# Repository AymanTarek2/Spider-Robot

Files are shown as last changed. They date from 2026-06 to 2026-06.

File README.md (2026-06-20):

# Spider Robot — FreeRTOS-Controlled Quadruped

A 4-legged (12-DOF) walking robot built around an ESP32, with the full mechanical structure designed from scratch in SolidWorks — not a pre-made GrabCAD model. Each leg runs as an independent FreeRTOS task, giving the robot concurrent, non-blocking control over all four legs from a single microcontroller.

Spider pic

https://github.com/user-attachments/assets/da0e5ce1-07fc-4307-80b6-2c7e29078677

## Mechanical Design

The chassis, leg links, and head were modelled entirely in SolidWorks as an original design — full part files, the top-level assembly, and 3D-printable STLs are included in `Spider Solidworks/`. Each leg has 3 degrees of freedom (hip, knee, ankle), for 12 servo-driven joints total.

## Embedded Architecture

The robot is built on an ESP32 (`esp32doit-devkit-v1`) using FreeRTOS as the real-time scheduler, with all 12 servos driven through a PCA9685 PWM driver over I2C.

**Per-leg concurrency.** Each leg is its own FreeRTOS task (`Leg_1`–`Leg_4`), created with `xTaskCreate` at equal priority and left running an infinite loop. There's no central gait-sequencer dictating timing to the legs — each task independently reads a shared `movement_states` struct (forward / backward / left / right) and drives its own 3-joint motion sequence. Walking gait emerges from staggering each task's startup delay (0 ms, 600 ms, 900 ms, 300 ms), which phase-offsets the legs relative to each other.

**Non-blocking timing.** Every wait in the motion code uses `vTaskDelay()` rather than a blocking `delay()`, so the scheduler can interleave all four leg tasks on the single core without one leg stalling the others.

**Low-level PWM driver.** The PCA9685 driver is written directly against the I2C register map (mode/prescale/PWM registers) rather than using an off-the-shelf servo library — `pca9685_set_pwm_freq`, `pca9685_set_pwm`, and `set_servo_angle` handle frequency configuration and per-channel pulse-width control for all 12 channels.

**Motion primitives.** `angle_motion()` steps three joint angles toward a target simultaneously, and `move_spider_leg()` chains three of these calls (lift, swing, plant) into one leg-stride cycle, parameterized by direction sign and step delay.

**App control (currently disabled).** The firmware includes Blynk/Wi-Fi integration (`BLYNK_WRITE` handlers mapped to the same four movement flags) for phone-app control, but this path is commented out in the current build — the robot currently runs from the `movement_states` flags directly rather than over Wi-Fi.

## Tech Stack

- **MCU:** ESP32 (Arduino framework via PlatformIO)
- **RTOS:** FreeRTOS (per-leg tasks, `vTaskDelay`-based scheduling)
- **Actuation:** 12x servo motors via PCA9685 PWM driver (I2C, custom register-level driver)
- **Connectivity:** Blynk/Wi-Fi (implemented, currently disabled in firmware)
- **Mechanical design:** SolidWorks (original design), 3D-printed structure

## Repository Structure

```
Spider Code/        PlatformIO project - ESP32 firmware
  src/main.cpp       Entry point, Blynk handlers, movement_states
  src/main.c          Servo driver, gait logic, FreeRTOS leg tasks
  src/movement_states.h

Spider Solidworks/  Original CAD - parts, assembly, and STLs for 3D printing
```

## Status

This was a personal hardware project - full design-to-deployment cycle from CAD through 3D printing to embedded firmware on real hardware.

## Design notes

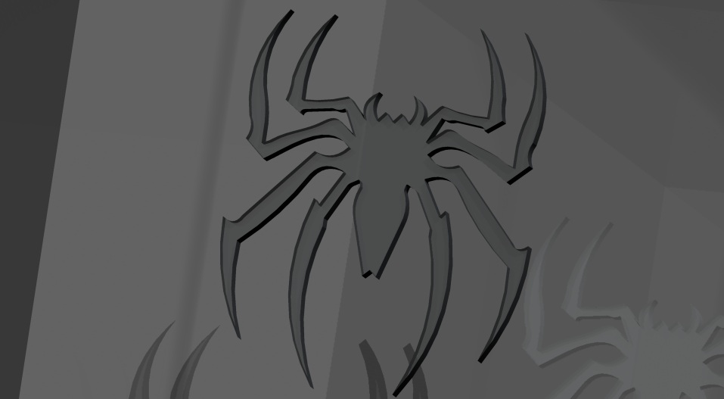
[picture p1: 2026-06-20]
Spider Solidworks/Renderings/sp1.jpg

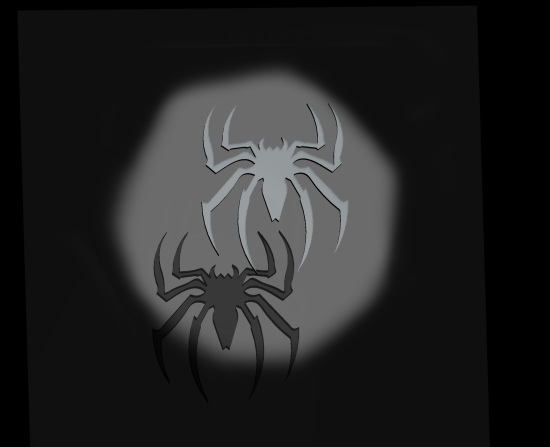
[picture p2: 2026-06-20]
Spider Solidworks/Renderings/ss2.jpg

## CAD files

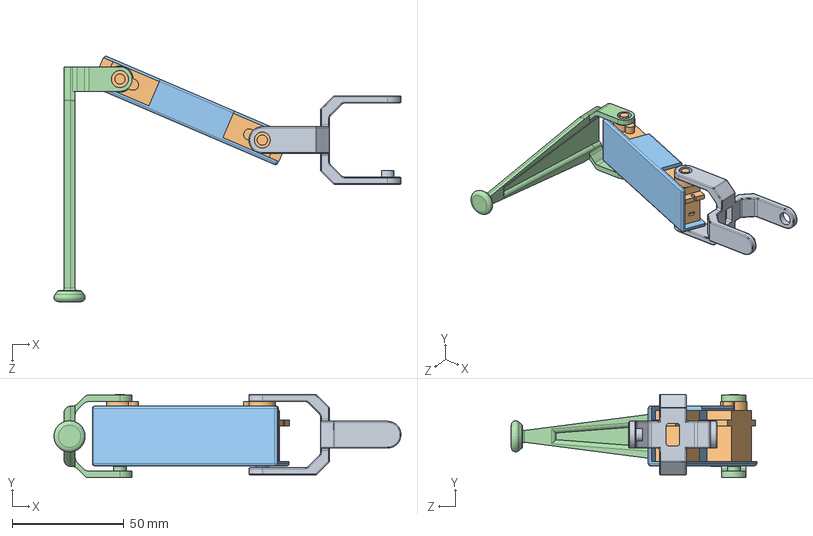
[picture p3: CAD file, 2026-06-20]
Spider Solidworks/Spider Arm.SLDASM
155.0 x 37.3 x 109.7 mm
Link1
User Library-Servo9G x 2
Link2
link3

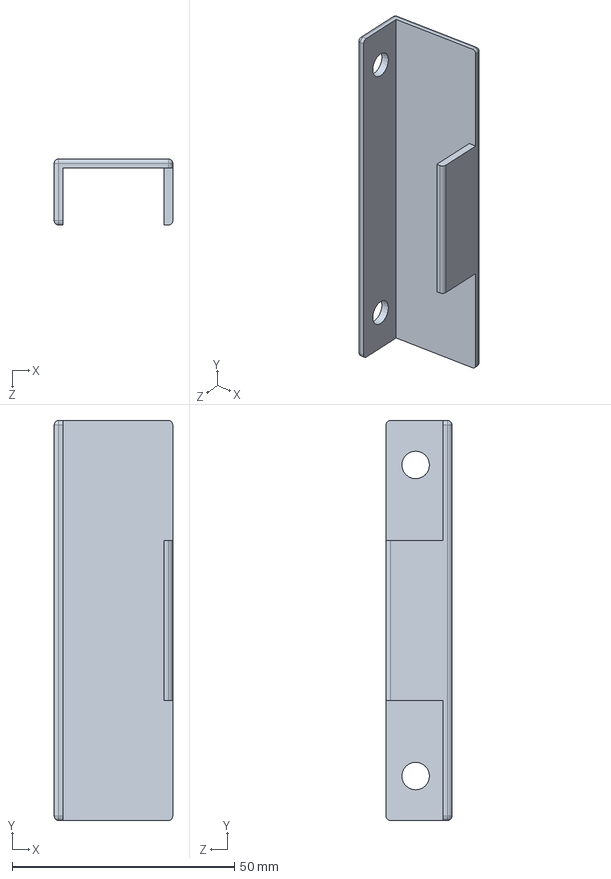
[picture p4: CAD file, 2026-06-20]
Spider Solidworks/Link2.SLDPRT
26.7 x 90.0 x 14.9 mm

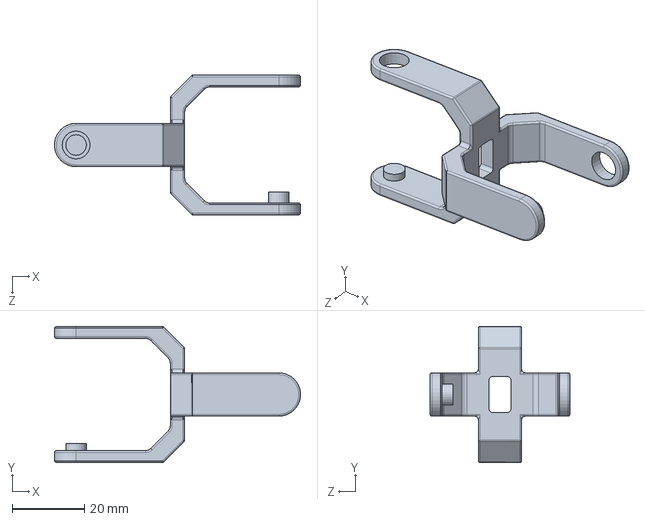
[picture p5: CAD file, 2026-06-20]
Spider Solidworks/Spider Robot stl 2/Link1.SLDPRT
67.9 x 37.6 x 38.6 mm

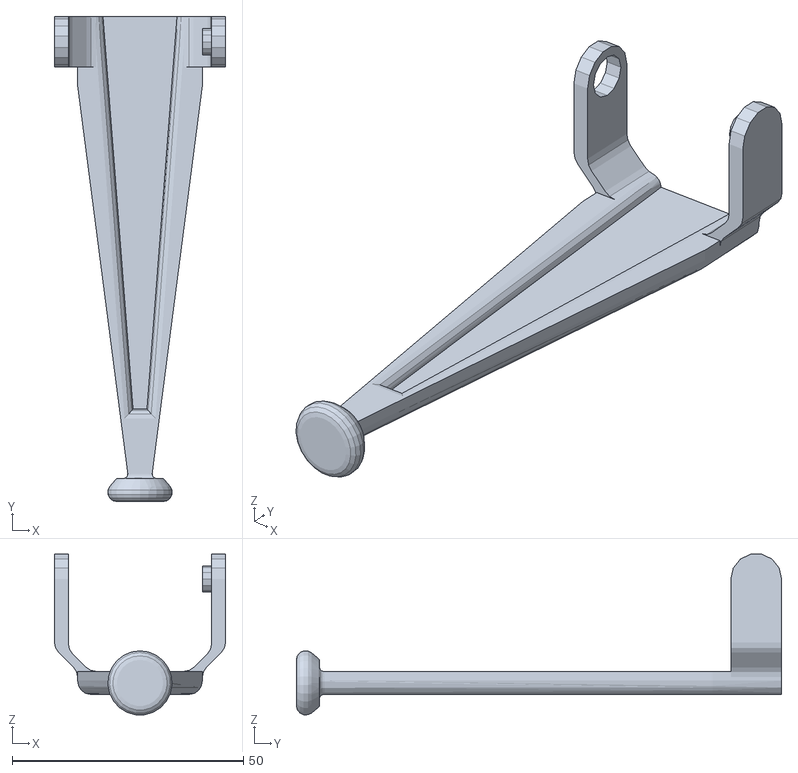
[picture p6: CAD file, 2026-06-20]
Spider Solidworks/Spider Robot stl 2/spider 3d print #4/link3 x4 .STL
37.0 x 105.0 x 34.8

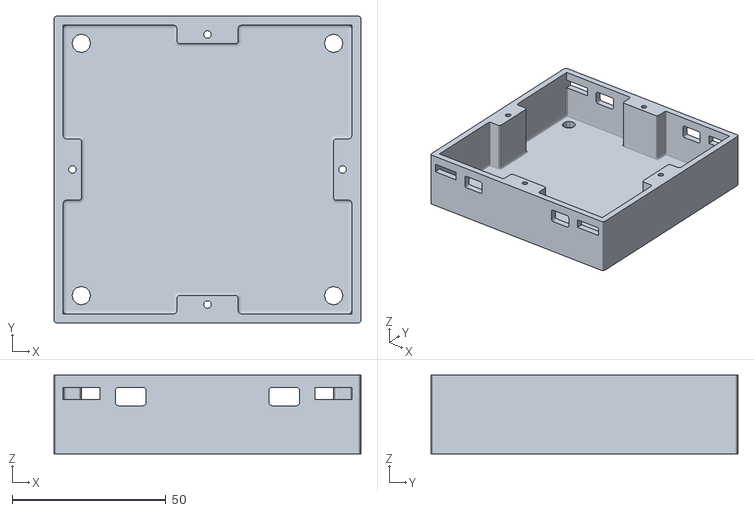
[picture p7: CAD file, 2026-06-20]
Spider Solidworks/Spider Robot stl/Body.STL
100.0 x 100.0 x 25.7

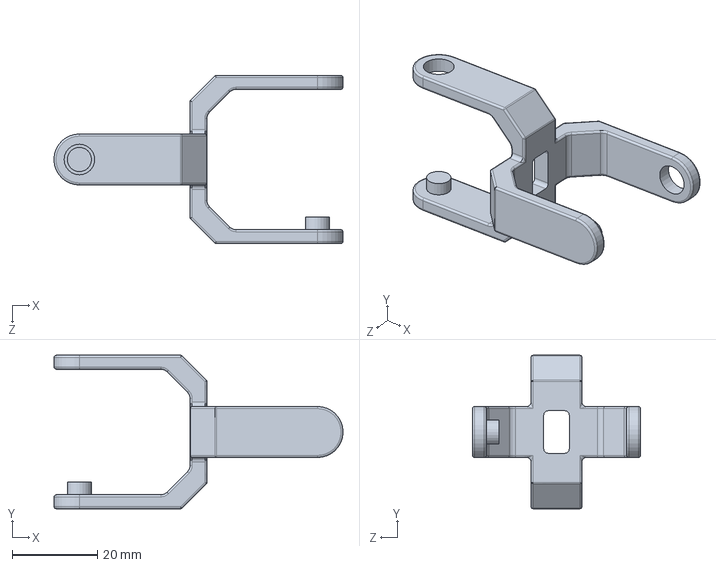
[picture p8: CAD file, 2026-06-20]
Spider Solidworks/Link1.SLDPRT
67.9 x 36.1 x 39.6 mm

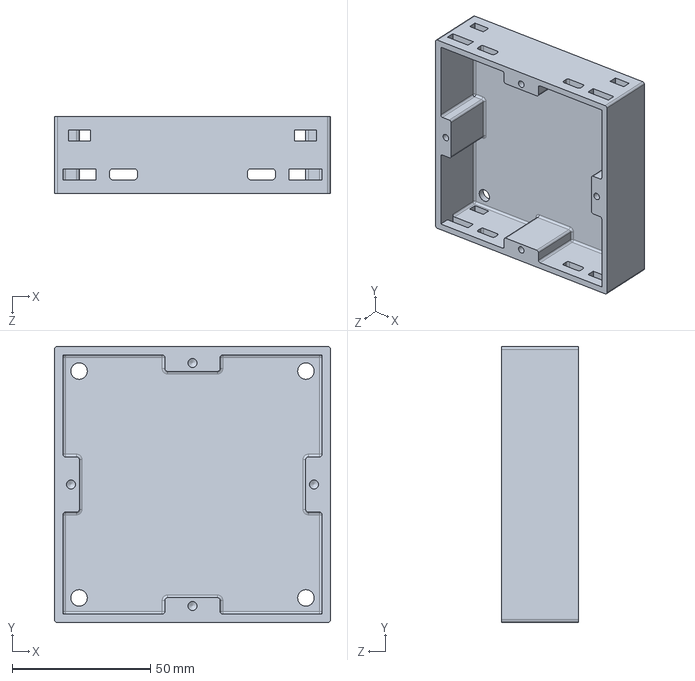
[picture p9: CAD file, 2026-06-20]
Spider Solidworks/Spider Robot stl 2/Body.SLDPRT
100.0 x 100.0 x 28.0 mm

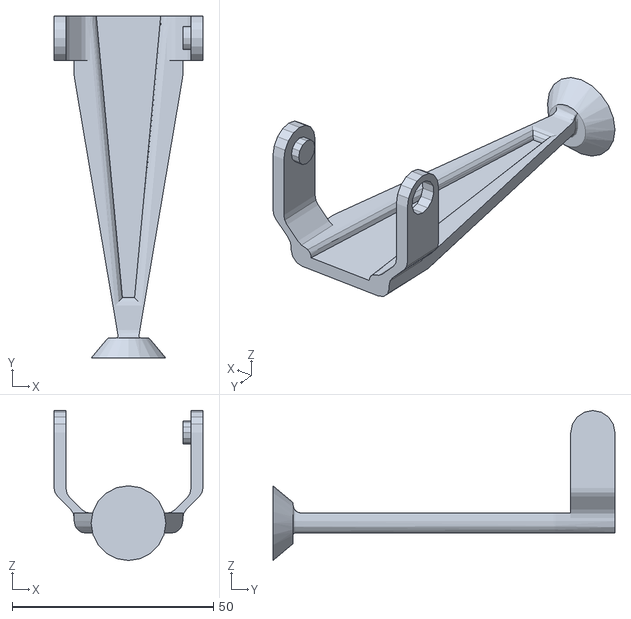
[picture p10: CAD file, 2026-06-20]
Spider Solidworks/Spider Robot stl 2/spider 3d print #3/link3.STL
37.0 x 85.0 x 37.3

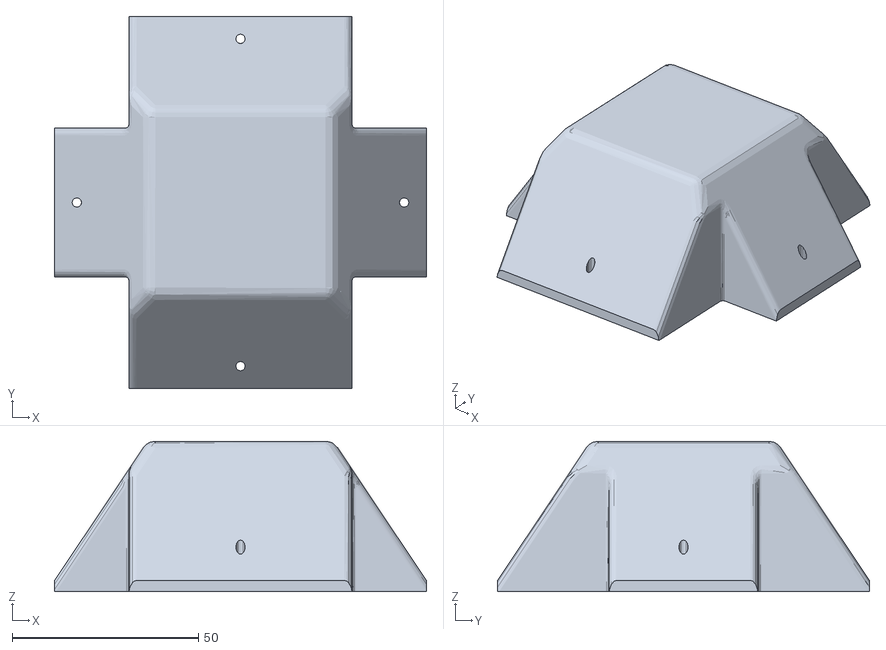
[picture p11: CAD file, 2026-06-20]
Spider Solidworks/Spider Robot stl/Upper Body.STL
100.0 x 100.0 x 40.4

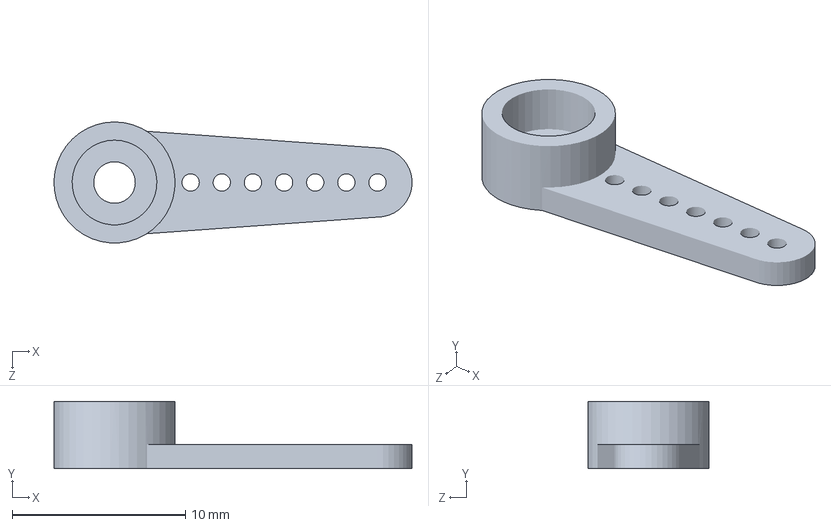
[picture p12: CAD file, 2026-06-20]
Spider Solidworks/microservoArmA3.SLDPRT
20.7 x 3.90 x 7.00 mm

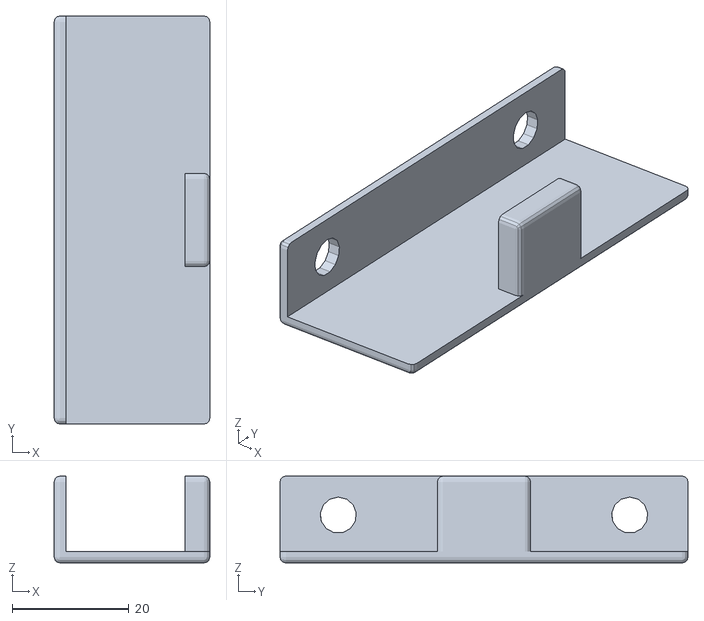
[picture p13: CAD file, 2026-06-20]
Spider Solidworks/Spider Robot stl 2/spider 3d print #3/Link2.STL
26.7 x 70.0 x 14.9

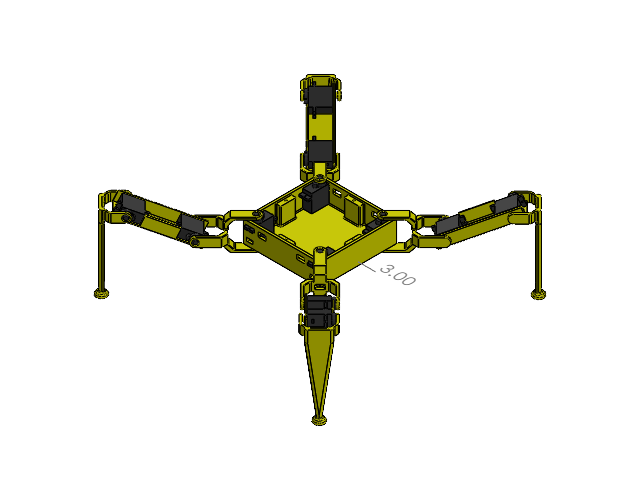
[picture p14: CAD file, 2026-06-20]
Spider Solidworks/Spider Robot.SLDASM
Link1 x 4
User Library-Servo9G x 12
Link2 x 4
link3 x 4

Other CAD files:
Spider Solidworks/Spider Robot stl 2/spider 3d print #2/Link2.STL
Spider Solidworks/Spider Robot stl 2/spider 3d print #3/Link1.STL
Spider Solidworks/Spider Robot stl 2/spider 3d print #2/Link1.STL
Spider Solidworks/Spider Robot stl 2/spider 3d print #4/Link1 x3 .STL
Spider Solidworks/Spider Robot stl 2/link3.SLDPRT
Spider Solidworks/Spider Robot stl 2/spider 3d print #2/Body.STL
Spider Solidworks/Body.SLDPRT
Spider Solidworks/Spider Head.SLDPRT
Spider Solidworks/Spider Head.STL
Spider Solidworks/Spider Robot stl 2/Link2.SLDPRT
Spider Solidworks/Spider Robot stl 2/spider 3d print #2/link3.STL
Spider Solidworks/Spider Robot stl/Link1 x4 .STL
Spider Solidworks/Spider Robot stl/Link2 x4 .STL
Spider Solidworks/Spider Robot stl/Link3 x4 .STL
Spider Solidworks/Upper Body.SLDPRT
Spider Solidworks/User Library-Servo9G.sldprt
Spider Solidworks/link1 (2).SLDPRT

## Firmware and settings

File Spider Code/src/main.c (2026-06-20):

#include <stdio.h>
#include "freertos/FreeRTOS.h"
#include "freertos/task.h"
#include "driver/i2c.h"
#include "esp_wifi.h"
#include "movement_states.h"

// PCA9685 I2C address
#define PCA9685_ADDR 0x40

// PCA9685 registers
#define PCA9685_MODE1 0x00
#define PCA9685_PRESCALE 0xFE

// I2C configuration
#define I2C_MASTER_SCL_IO 22
#define I2C_MASTER_SDA_IO 21
#define I2C_MASTER_NUM I2C_NUM_0
#define I2C_MASTER_FREQ_HZ 100000
#define I2C_MASTER_TX_BUF_DISABLE 0
#define I2C_MASTER_RX_BUF_DISABLE 0

#define ang 30

int current_angles[12];
uint8_t origin_angles[12] = {45, 130 - ang, 155 - ang, 45, 160 - ang, 175 - ang, 45, 180 - ang, 180 - ang, 55, 160 - ang, 160 - ang};

extern MovementStates movement_states;

int legs[4] = {0, 1, 2, 3};
int fastDelay = 8;
int slowDelay = 40;


void i2c_master_init()
{
    // Initialize I2C
    i2c_config_t conf = {
        .mode = I2C_MODE_MASTER,
        .sda_io_num = I2C_MASTER_SDA_IO,
        .sda_pullup_en = GPIO_PULLUP_ENABLE,
        .scl_io_num = I2C_MASTER_SCL_IO,
        .scl_pullup_en = GPIO_PULLUP_ENABLE,
        .master.clk_speed = I2C_MASTER_FREQ_HZ,
    };
    i2c_param_config(I2C_MASTER_NUM, &conf);
    i2c_driver_install(I2C_MASTER_NUM, conf.mode, I2C_MASTER_RX_BUF_DISABLE, I2C_MASTER_TX_BUF_DISABLE, 0);
}

// Function to write a value to a register
esp_err_t pca9685_write_register(uint8_t reg, uint8_t value)
{
    i2c_cmd_handle_t cmd = i2c_cmd_link_create();
    i2c_master_start(cmd);
    i2c_master_write_byte(cmd, (PCA9685_ADDR << 1) | I2C_MASTER_WRITE, true);
    i2c_master_write_byte(cmd, reg, true);
    i2c_master_write_byte(cmd, value, true);
    i2c_master_stop(cmd);
    esp_err_t ret = i2c_master_cmd_begin(I2C_MASTER_NUM, cmd, pdMS_TO_TICKS(1000));
    i2c_cmd_link_delete(cmd);
    return ret;
}

// Function to set PWM frequency
void pca9685_set_pwm_freq(float freq)
{
    uint8_t prescale_val = (uint8_t)(25000000.0 / (4096.0 * freq) - 1.0);
    pca9685_write_register(PCA9685_MODE1, 0x10); // Sleep mode
    pca9685_write_register(PCA9685_PRESCALE, prescale_val);
    pca9685_write_register(PCA9685_MODE1, 0x80); // Restart
    vTaskDelay(pdMS_TO_TICKS(5));
    pca9685_write_register(PCA9685_MODE1, 0x00); // Normal mode
}

// Function to set PWM value for a channel
void pca9685_set_pwm(uint8_t channel, uint16_t on, uint16_t off)
{
    uint8_t reg = 0x06 + 4 * channel;
    pca9685_write_register(reg, on & 0xFF);
    pca9685_write_register(reg + 1, on >> 8);
    pca9685_write_register(reg + 2, off & 0xFF);
    pca9685_write_register(reg + 3, off >> 8);
}

void set_servo_angle(uint8_t channel, uint16_t angle)
{
    uint16_t pulse = 150 + angle * 2.275;
    pca9685_set_pwm(channel, 0, pulse);
}

void reset_servos()
{
    for (uint8_t i = 0; i < 12; i++)
    {
        set_servo_angle(i, origin_angles[i]);
        current_angles[i] = origin_angles[i];
    }
    printf("reset here\n");
}

void spider_init()
{
    i2c_master_init();
    pca9685_set_pwm_freq(50);
    reset_servos();
}


void angle_motion(int initialPin, int angles[3], int delay)
{
    // loops on every angle until it reaches zero while being applied to its corresponding servo
    int steps[3];
    for (int i = 0; i < 3; i++)
        steps[i] = (angles[i] > 0) ? 2 : -2; // sets the sign of angle change

    while (angles[0] != 0 || angles[1] != 0 || angles[2] != 0)
    {
        for (int i = 0; i < 3; i++)
        {
            if (angles[i] != 0)
            {
                set_servo_angle(initialPin + i, current_angles[initialPin + i] += steps[i]);
                angles[i] -= steps[i];
            }
        }

        vTaskDelay(pdMS_TO_TICKS(delay));
    }
}


void move_spider_leg(int initialPin, int sign, int angleInc)
{
    if(sign == 0)
    {
        vTaskDelay(pdMS_TO_TICKS(500)); 
        return;
    }

    angle_motion(initialPin, (int[]){40 * sign, 32, 32 - angleInc}, fastDelay);
    angle_motion(initialPin, (int[]){0, -32, -32}, fastDelay);
    angle_motion(initialPin, (int[]){-40 * sign, 0, 20}, slowDelay);
}


void leg_task(int leg, int delay)
{
    int initialPin = leg * 3;
    int sign = 0;
    int angleInc = 0;
    uint8_t lastState = 0;

    //movement_states.forward = 1;

    while (1)
    {
        uint8_t currentState = movement_states.forward || movement_states.backward || movement_states.right || movement_states.left;

        if (currentState && !lastState)
        {
            (movement_states.forward)  ? angle_motion(initialPin, (int[]){-22 * (sign = (leg % 2 == 0) ? 1 : -1), 0, 0}, slowDelay) :
            (movement_states.backward) ? angle_motion(initialPin, (int[]){22 * (sign = (leg % 2 == 0) ? -1 : 1), 0, 0}, slowDelay) : (void) 0;

            vTaskDelay(pdMS_TO_TICKS(delay));
            angleInc = 0;
        }

        // if-else ternary structure, chooses one of the 4 movement states to set the corresponding leg direction
        (movement_states.forward)  ? (sign = (leg % 2 == 0) ? 1 : -1) :
        (movement_states.backward) ? (sign = (leg % 2 == 0) ? -1 : 1) :
        (movement_states.right)    ? sign = 1 :
        (movement_states.left)     ? sign = -1 : 0;

        move_spider_leg(initialPin, sign, angleInc);

        lastState = currentState;
        angleInc = 20;
    }
}


void Leg_1(void *pvParameters)
{
    leg_task(0, 0);
}

void Leg_2(void *pvParameters)
{
    leg_task(1, 600);
}

void Leg_3(void *pvParameters)
{
    leg_task(2, 900);
}

void Leg_4(void *pvParameters)
{
    leg_task(3, 300);
}


void spider()
{
    i2c_master_init();
    pca9685_set_pwm_freq(50);
    reset_servos();
    
    vTaskDelay(pdMS_TO_TICKS(3000));

    xTaskCreate(Leg_1, "Leg 1", 2048, NULL, configMAX_PRIORITIES - 1, NULL);
    xTaskCreate(Leg_2, "Leg 2", 2048, NULL, configMAX_PRIORITIES - 1, NULL);
    xTaskCreate(Leg_3, "Leg 3", 2048, NULL, configMAX_PRIORITIES - 1, NULL);
    xTaskCreate(Leg_4, "Leg 4", 2048, NULL, configMAX_PRIORITIES - 1, NULL);
}

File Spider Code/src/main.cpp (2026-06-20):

#define BLYNK_TEMPLATE_ID "TMPL2grVroM2L"
#define BLYNK_TEMPLATE_NAME "LED"
#define BLYNK_AUTH_TOKEN "_1G-pvBF2hPhJFonha-P9gcWOeT09yiv"

#define BLYNK_PRINT Serial

#include <WiFi.h>
#include <WiFiClient.h>
#include <BlynkSimpleEsp32.h>
#include "movement_states.h"

// Network credentials
char ssid[] = "Orange-mtsasb";
char pass[] = "Mt$a$b1964";

// Blynk auth token
char auth[] = "_1G-pvBF2hPhJFonha-P9gcWOeT09yiv";

const int pin = 2;

MovementStates movement_states = {0, 0, 0, 0};

extern "C"
{
  void spider();
  void reset_servos();
}

BLYNK_WRITE(V0)
{ // Button 1 - Move Forward
  (movement_states.forward = param.asInt()) ? (void)0 : reset_servos();
}

BLYNK_WRITE(V1)
{ // Button 2 - Move Backward
  (movement_states.backward = param.asInt()) ? (void)0 : reset_servos();
}

BLYNK_WRITE(V2)
{ // Button 3 - Rotate Right
  (movement_states.right = param.asInt()) ? (void)0 : reset_servos();
}

BLYNK_WRITE(V4)
{ // Button 4 - Rotate Left
  (movement_states.left = param.asInt()) ? (void)0 : reset_servos();
}

void setup()
{
  Serial.begin(115200);

  // Set GPIO 4 as output
  pinMode(pin, OUTPUT);
  digitalWrite(pin, LOW);
  
  //Blynk.begin(auth, ssid, pass);

  spider();
}

void loop()
{
  //Blynk.run();
  // Serial.print("Forward: ");
  // Serial.print(movement_states.forward);
  // Serial.print(" | Backward: ");
  // Serial.print(movement_states.backward);
  // Serial.print(" | Rotate Right: ");
  // Serial.print(movement_states.right);
  // Serial.print(" | Rotate Left: ");
  // Serial.println(movement_states.left);

  //delay(500);
}
